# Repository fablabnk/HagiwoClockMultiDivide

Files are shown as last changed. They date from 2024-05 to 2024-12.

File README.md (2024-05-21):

This is an attempt to make a PCB version of [Hagiwo's Clock Multi Divide module](https://note.com/solder_state/n/n8907f2f6e8f5).

# Notes / ToDo

- I'm using the schematic symbol for Arduino Nano v3.x, check that this matches my actual Nano
- Change pin order of Eurocad 2x5 pin power symbol
- Update screw hole positions on panel template - mine fall between two rail screw holes
    - centre is: 3mm down from edge, 5.08mm across from edge, 3.2 in diameter, seems correct

## Diodes and voltage protection

Which diodes protect against which things? Original text says that the circuit:
1. Does not break due to overvoltage
2. Does not break due to negative voltage
3. Does not break due to overcurrent
4. External clock does not enter the internal clock output
5. Internal clock output does not enter the external clock input
But which diodes do which things?

These diodes are there for protecting the arduino if you plug something in that sends voltages it can’t handle.
Everything negative will go to ground thru one set of diodes, everything over 5V will go to the 5V rail thru the other set.
Out has only one diode because there is already one on pin D13.

## Power

- Arduino is given VIN of 12V? Or is it somehow powered from the 5V rail?
- I notice Higawo uses a 16 pin connector
- But Arduino Nano operating range is quoted as 7-12V
- Should we connect capacitors to the +-12V power connector rails?

## Updating the schematic

There were some small issues with the original Hagiwo schematic. I made the following changes in my KiCad schematic:
- in the External Clock In section, there should be a dot connecting two vertical BAT43 diodes
According to the discussion [here](https://lookmumnocomputer.discourse.group/t/arduino-clock-multiple-divider/2612/3), for the Master Clock Out section:
- The initial diode after Arduino pin D13 should be a small signal diode (IN4148 or similiar)
- The SchottKey diode following the 470 Ohm resistor should actually come before the resistor

## PCB Issues

- My SPDT switch is not board mountable and will need to be wired to the board instead. So I used the footprint "TerminalBlock:TerminalBlock_bornier-3_P5.08mm"
- The Arduino nano will be mounted to the front of the PCB using pin headers

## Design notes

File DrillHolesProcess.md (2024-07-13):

# [NEW]

File -> Plot
Choose "Plot Format" SVG
Choose "Drill Marks" -> Actual Size
Tick "Sketch pads on Fabrication Layers"
In "Include Layers" section tick only "F Silkscreen"
In "Plot on All Layers" tick "Edge Cuts"
Set correct output directory at top (relative path)
Click "Plot" button, one file should be generated called "F Silkscreen"
In "Include Layers" section tick only "B Silkscreen"
In "Plot on All Layers" tick nothing
Load both files into Inkscape, tidy, make holes RGB 255 255 255 0 and 0.01mm thick with 75% power and 1 speed. Make silkcreen text RGB 0 0 0 0 and 0.01mm thick with 40% power and 1 speed. The former cuts through, latter cuts surface only
Only the former (front) file has/cuts holes border, the back file should have only silkscreening
Laser cut front file, flip the cut over in place (in the rectangular hole that was created), then laser cut back file

# [OLD] Process for exporting drill holes as SVG format for test laser cutting

In pcb editor choose File -> Plot -> Generate Drill Files: name-NPTH.drl and name-PTH.drl files will be made

double click project_name-NPTH.drl in project file window to open in gerber viewer
File -> Export to PCB Editor
save as NPTH.kicad_pcb
when `Layer Selection` box pops up, click three dots ... and choose Edge.Cuts layer, then click OK
open NPTH.kicad_pcb in project file window, choose File -> Plot, choose Plot Format `SVG`, Include Layers `Edge.Cuts` only and click Plot

repeat above steps for PTH.drl

open each file in SVG

Don't forget to plot also the actual Edge Cuts layer from the original project in the same way as above i.e.
- File -> Plot, choose Plot Format `SVG`, Include Layers `Edge.Cuts` only and click Plot

Now you have three .svg files
project_name-Edge_Cuts.svg
npth-Edge_Cuts.svg
pth-Edge_Cut.svg

Combine in Illustrator and cut all as red thin lines

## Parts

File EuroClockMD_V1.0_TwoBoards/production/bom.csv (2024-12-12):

Designator | Footprint | Quantity | Value | LCSC Part #
A1 | Arduino_Nano | 1 | Arduino_Nano_v3.x
C1, C2 | C_Disc_D3.0mm_W1.6mm_P2.50mm | 2 | 220p
D1, D10, D11, D12, D3, D4, D5, D8 | D_DO-35_SOD27_P7.62mm_Horizontal | 8 | BAT43
D2 | LED_D5.0mm | 1 | GATE OUT 1 LED
D6 | LED_D5.0mm | 1 | GATE OUT 2 LED
D7 | D_DO-35_SOD27_P7.62mm_Horizontal | 1 | IN4148
D9 | LED_D5.0mm | 1 | CLOCK OUT LED
J1 | PJ301M-12_T_S | 1 | GATE OUT 1
J2 | PJ301M-12_T_S | 1 | GATE OUT 2
J3 | PJ301M-12_T_S | 1 | CLOCK OUT
J4 | PJ301M-12_T_S | 1 | EXT CLK IN
J5 | IDC-Header_2x05_P2.54mm_Vertical | 1 | EURO_PWR_2x5
J6 | PinHeader_1x15_P2.54mm_Vertical | 1 | Conn_01x15_Pin_Left
J7 | PinSocket_1x15_P2.54mm_Vertical | 1 | Conn_01x15_Socket_Left
J8 | PinSocket_1x15_P2.54mm_Vertical | 1 | Conn_01x15_Socket_Right
J9 | PinHeader_1x15_P2.54mm_Vertical | 1 | Conn_01x15_Pin_Right
R1, R3, R4, R6, R7, R9 | R_Axial_DIN0207_L6.3mm_D2.5mm_P7.62mm_Horizontal | 6 | 470
R10, R2, R5, R8 | R_Axial_DIN0207_L6.3mm_D2.5mm_P7.62mm_Horizontal | 4 | 22K
RV1 | Alpha9mmPot | 1 | 100K MULTI/DIV
RV2 | Alpha9mmPot | 1 | 100K RATE
SW1 | SW_Slide-03_Wuerth-WS-SLTV_10x2.5x6.4_P2.54mm | 1 | SW_SPDT (Internal Pullup)

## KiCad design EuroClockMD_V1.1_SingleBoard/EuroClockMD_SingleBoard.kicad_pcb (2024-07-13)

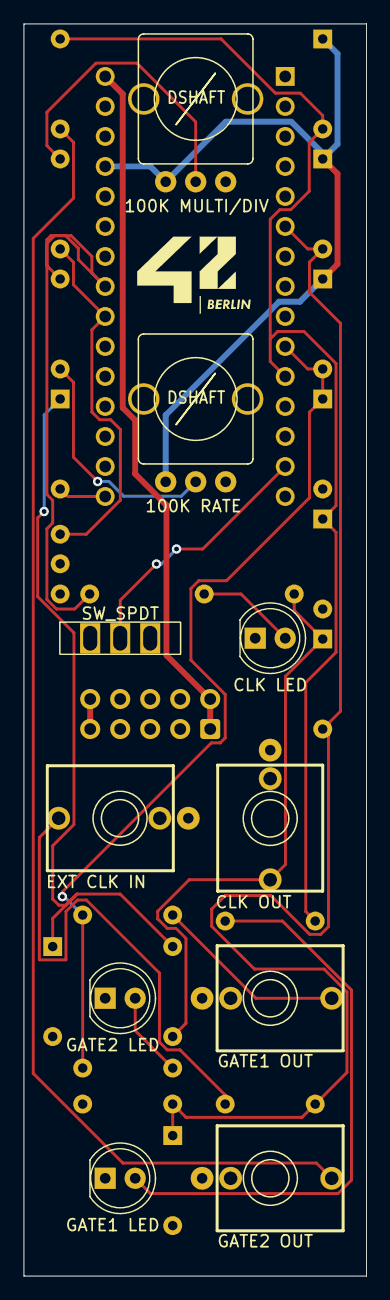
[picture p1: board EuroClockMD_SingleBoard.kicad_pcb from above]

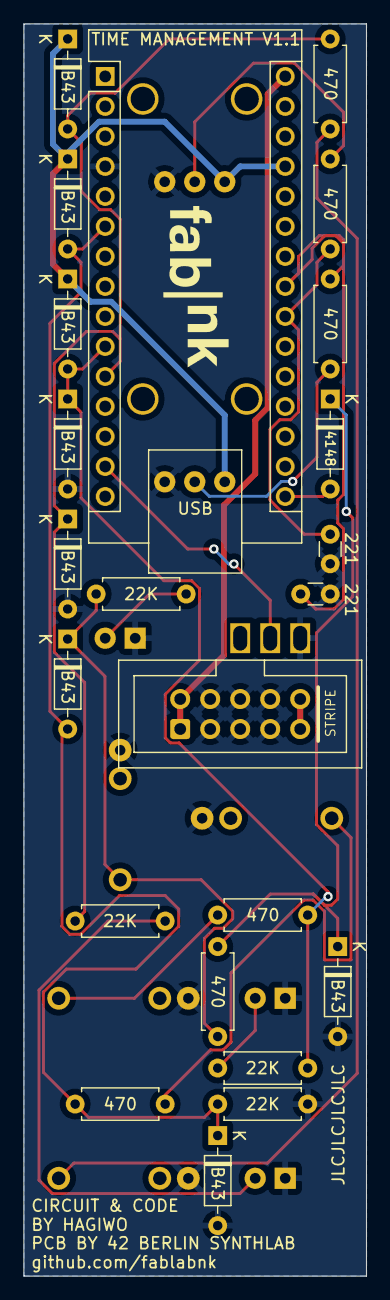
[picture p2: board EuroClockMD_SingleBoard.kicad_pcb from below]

Board: 2 copper layers, 29.0 x 106.0 mm, 33 parts (23 on the bottom side), 20 nets.

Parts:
A1: Arduino_Nano_v3.x; Arduino_Nano
C1, C2: 221; C_Disc_D3.0mm_W1.6mm_P2.50mm
D1, D3, D4, D5, D8, D10, D11, D12: B43; D_DO-35_SOD27_P7.62mm_Horizontal
D2: GATE2 LED; LED_D5.0mm
D6: GATE1 LED; LED_D5.0mm
D7: 4148; D_DO-35_SOD27_P7.62mm_Horizontal
D9: CLK LED; LED_D5.0mm
J1: GATE1 OUT; EighthInch_PJ398SM_T_TN_S
J2: GATE2 OUT; EighthInch_PJ398SM_T_TN_S
J3: CLK OUT; EighthInch_PJ398SM_T_TN_S
J4: EXT CLK IN; EighthInch_PJ398SM_T_TN_S
J5: EURO_PWR_2x5; IDC-Header_2x05_P2.54mm_Vertical_Euro_Power_Striped
R1, R3, R4, R6, R7, R9: 470; R_Axial_DIN0207_L6.3mm_D2.5mm_P7.62mm_Horizontal
R2, R5, R8, R10: 22K; R_Axial_DIN0207_L6.3mm_D2.5mm_P7.62mm_Horizontal
RV1: 100K MULTI/DIV; Pot_9mm_DShaft_RemovedPins4_5
RV2: 100K RATE; Pot_9mm_DShaft_RemovedPins4_5
SW1: SW_SPDT; SW_Slide-03_Wuerth-WS-SLTV_10x2.5x6.4_P2.54mm

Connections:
+5V: A1.27 (+5V), D1.1 (K), D4.1 (K), D10.1 (K), RV1.1, RV2.1
GND: A1.4 (GND), C1.2, C2.2, D2.1 (K), D3.2 (A), D5.2 (A), D6.1 (K), D8.2 (A), D9.1 (K), D11.2 (A), J1.S, J2.S, J3.S, J4.S, J5.3 (GND), J5.4 (GND), J5.5 (GND), J5.6 (GND), J5.7 (GND), J5.8 (GND), R10.2, RV1.3, RV2.3, SW1.2 (B)
unnamed: A1.22 (A3), C1.1, R1.2
unnamed: A1.23 (A4), C2.1, R6.2
unnamed: A1.6 (D3), D10.2 (A), D11.1 (K), D12.2 (A), R9.2, R10.1
unnamed: A1.10 (D7), D3.1 (K), D4.2 (A), R2.2, R3.1
unnamed: A1.11 (D8), D1.2 (A), D5.1 (K), R5.2, R7.1
unnamed: A1.14 (D11), SW1.1 (A)
unnamed: A1.16 (D13), D7.2 (A)
unnamed: A1.30 (VIN), J5.1 (+12V), J5.2 (+12V)
unnamed: D2.2 (A), R2.1
unnamed: D6.2 (A), R5.1
unnamed: D7.1 (K), D8.1 (K), R4.1
unnamed: D9.2 (A), R8.1
unnamed: D12.1 (K), J3.T, R4.2, R8.2
unnamed: J1.T, R3.2
unnamed: J2.T, R7.2
unnamed: J4.T, R9.1
unnamed: R1.1, RV1.2
unnamed: R6.1, RV2.2

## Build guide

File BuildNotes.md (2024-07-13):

- The Arduino should be mounted on pin headers, not soldered directly to the board
- In general, mount and solder the components on the back of the board first
- The one exception is the pin headers, which should be soldered last, as they hinder access to pads for pots
- We also must take care to solder the power connector before soldering the CLK OUT jack
- This is because one pad (S - sleeve) of the CLK OUT cuts into the courtyard of the power connector
- In addition, the CLK OUT S (sleeve) might have to be soldered from front of board (only)

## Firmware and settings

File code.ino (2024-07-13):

//Clock M_D module
#include <MsTimer2.h>

unsigned long ext_count = 400;//タイマーカウント用
unsigned long old_ext_pulse = 0;
unsigned long old_int_pulse = 0;
unsigned long ext_period = 0;//周期
unsigned long ext_count_result = 0;//タイマーのカウント結果
unsigned long old_ext_count_result = 0;//タイマーのカウント結果
byte ext_pulse = 0;//外部クロック　あれば1、なければ0
byte int_pulse = 0;//内部クロック
byte ext_injudge = 1;//外部入力有無判定。あれば1,なければ0。タイマーカウントが規定値超えると判定切り替え
byte old_ext_injudge = 2;

int AD_rate = 512;//rateノブの入力
int rate = 1000;//内部クロック動作時に使用

int AD_MD = 512;//MDノブの入力値
int out_width_ch1 = 10;//アウトプットのパルス幅。
int out_width_ch2 = 10;//アウトプットのパルス幅。
int old_AD_MD = 512;//SW切り替え時のRATE値誤読対策
int MD_ch1 = 5;//マルチプル、ディバイダー判定ch1
int MD_ch2 = 5;//マルチプル、ディバイダー判定ch2
int M_period_ch1 = 0;//マルチプルの時、出力クロックの周期。マルチプルでなければ0とする。
int M_period_ch2 = 0;//マルチプルの時、出力クロックの周期。マルチプルでなければ0とする。
int M_count_ch1 = 1;//マルチプルの時、パルスごとにカウントし、設定値に達すると0に戻る
int M_count_ch2 = 1;//マルチプルの時、パルスごとにカウントし、設定値に達すると0に戻る
int D_count_ch1 = 1;//外部パルスが入るとカウントを位置上げる
int D_count_ch2 = 1;//外部パルスが入るとカウントを位置上げる
int D_full_ch1 = 1;//カウントの上限値
int D_full_ch2 = 1;//カウントの上限値
byte CH1out = 0;//0でLOW出力、1でHIGH出力
byte CH2out = 0;//0でLOW出力、1でHIGH出力
byte M_done_ch1 = 0; //マルチプルの出力確認用。ないと、1クロックで複数パルスでてしまう
byte M_done_ch2 = 0; //マルチプルの出力確認用。ないと、1クロックで複数パルスでてしまう


//---mode切り替え-------------
byte mode_sw = 1;
byte mode = 1;//1=CH1,2=CH2
byte old_mode = 0;//SW切り替え時のRATE値誤読対策
int old_MD_ch1 = 0;//スイッチ切り替え時にディバイダーのクロックが狂うバグ対策
int old_MD_ch2 = 0;//スイッチ切り替え時にディバイダーのクロックが狂うバグ対策

void setup() {
 pinMode(7, OUTPUT); //CH1out
 pinMode(8, OUTPUT); //CH2out
 pinMode(13, OUTPUT); //internal_clock_out
 pinMode(11, INPUT_PULLUP); //SW
 pinMode(3, INPUT); //ext_clock_in
 Serial.begin(9600);

 MsTimer2::set(1, timer_count); // 1ms毎にタイマーカウント
 MsTimer2::start();//外部入力Highになったら、次のHighまでカウント
}

void loop() {
 AD_MD = analogRead(3);
 AD_rate = 1023 - analogRead(4);
 rate = AD_rate * 2 + 100;

 old_ext_pulse = ext_pulse;
 old_int_pulse = int_pulse;
 ext_pulse = digitalRead(3);

 mode_sw = digitalRead(11);
 old_mode = mode;

 old_ext_injudge = ext_injudge;

 //-----------ディバイダー出力のカウントリセット------------
 if (D_count_ch1 >= D_full_ch1) {
   D_count_ch1 = 0;
 }
 if (D_count_ch2 >= D_full_ch2) {
   D_count_ch2 = 0;
 }

 //-----------SWの読み取り---------------

 old_MD_ch1 = MD_ch1;//スイッチ切り替え時にディバイダーのクロックが狂うバグ対策
 old_MD_ch2 = MD_ch2;//スイッチ切り替え時にディバイダーのクロックが狂うバグ対策

 if ( mode_sw == 1  ) {
   mode = 1;
 }
 else if (mode_sw == 0  ) {
   mode = 2;
 }

 if ( old_mode != mode ) {//スイッチ切り替え時にディバイダーのクロックが狂うバグ対策
   old_AD_MD = AD_MD;
 }

 //---------MDノブ判定-----------------------

 if ( mode == 1 && abs(old_AD_MD - AD_MD ) > 30) { //absはスイッチ切り替え時にディバイダーのクロックが狂うバグ対策
   old_AD_MD = 1200;//abs(old_AD_MD - AD_MD ) > 30が絶対に成立するため

   if ( AD_MD >= 0 && AD_MD < 20) {
     MD_ch1 = 9;//*16
   }

   else if ( AD_MD >= 20 && AD_MD < 90) {
     MD_ch1 = 8;//*8
   }

   else if ( AD_MD >= 90 && AD_MD < 240) {
     MD_ch1 = 7;//*4
   }

   else if ( AD_MD >= 240 && AD_MD < 400) {
     MD_ch1 = 6;//*2
   }

   else if ( AD_MD >= 400 && AD_MD < 550) {
     MD_ch1 = 5;//*1
   }

   else if ( AD_MD >= 550 && AD_MD < 700) {
     MD_ch1 = 4;//1/2
   }

   else if ( AD_MD >= 700 && AD_MD < 820) {
     MD_ch1 = 3;//1/3
   }

   else if ( AD_MD >= 820 && AD_MD < 960) {
     MD_ch1 = 2;//1/4
   }

   else if ( AD_MD >= 960 && AD_MD < 1024) {
     MD_ch1 = 1;//1/8
   }
 }

 else if ( mode == 2 && abs(old_AD_MD - AD_MD ) > 30) {  //absはスイッチ切り替え時にディバイダーのクロックが狂うバグ対策
   old_AD_MD = 1200;//abs(old_AD_MD - AD_MD ) > 30が絶対に成立するため

   if ( AD_MD >= 0 && AD_MD < 20) {
     MD_ch2 = 9;//*16
   }

   else if ( AD_MD >= 20 && AD_MD < 90) {
     MD_ch2 = 8;//*8
   }

   else if ( AD_MD >= 90 && AD_MD < 240) {
     MD_ch2 = 7;//*4
   }

   else if ( AD_MD >= 240 && AD_MD < 400) {
     MD_ch2 = 6;//*2
   }

   else if ( AD_MD >= 400 && AD_MD < 550) {
     MD_ch2 = 5;//*1
   }

   else if ( AD_MD >= 550 && AD_MD < 700) {
     MD_ch2 = 4;//1/2
   }

   else if ( AD_MD >= 700 && AD_MD < 820) {
     MD_ch2 = 3;//1/3
   }

   else if ( AD_MD >= 820 && AD_MD < 960) {
     MD_ch2 = 2;//1/4
   }

   else if ( AD_MD >= 960 && AD_MD < 1024) {
     MD_ch2 = 1;//1/8
   }
 }


 switch (MD_ch1) {
   case 1:
     out_width_ch1 = ext_period / 2 / 8;
     M_period_ch1 = ext_period / 8;
     break;

   case 2:
     out_width_ch1 = ext_period / 2 / 4;
     M_period_ch1 = ext_period / 4;
     break;

   case 3:
     out_width_ch1 = ext_period / 2 / 3;
     M_period_ch1 = ext_period / 3;
     break;

   case 4:
     out_width_ch1 = ext_period / 2 / 2;
     M_period_ch1 = ext_period / 2;
     break;

   case 5:
     out_width_ch1 = ext_period / 2 ;
     M_period_ch1 = 0;
     D_full_ch1 = 1;
     break;

   case 6:
     out_width_ch1 = ext_period / 2;
     M_period_ch1 = 0;
     D_full_ch1 = 2;
     break;

   case 7:
     out_width_ch1 = ext_period / 2;
     M_period_ch1 = 0;
     D_full_ch1 = 4;
     break;

   case 8:
     out_width_ch1 = ext_period / 2;
     M_period_ch1 = 0;
     D_full_ch1 = 8;
     break;

   case 9:
     out_width_ch1 = ext_period / 2;
     M_period_ch1 = 0;
     D_full_ch1 = 16;
     break;
 }


 switch (MD_ch2) {
   case 1:
     out_width_ch2 = ext_period / 2 / 8;
     M_period_ch2 = ext_period / 8;
     break;

   case 2:
     out_width_ch2 = ext_period / 2 / 4;
     M_period_ch2 = ext_period / 4;
     break;

   case 3:
     out_width_ch2 = ext_period / 2 / 3;
     M_period_ch2 = ext_period / 3;
     break;

   case 4:
     out_width_ch2 = ext_period / 2 / 2;
     M_period_ch2 = ext_period / 2;
     break;

   case 5:
     out_width_ch2 = ext_period / 2 ;
     M_period_ch2 = 0;
     D_full_ch2 = 1;
     break;

   case 6:
     out_width_ch2 = ext_period / 2 ;
     M_period_ch2 = 0;
     D_full_ch2 = 2;
     break;

   case 7:
     out_width_ch2 = ext_period / 2 ;
     M_period_ch2 = 0;
     D_full_ch2 = 4;
     break;

   case 8:
     out_width_ch2 = ext_period / 2 ;
     M_period_ch2 = 0;
     D_full_ch2 = 8;
     break;

   case 9:
     out_width_ch2 = ext_period / 2 ;
     M_period_ch2 = 0;
     D_full_ch2 = 16;
     break;
 }

 if ( MD_ch1 != old_MD_ch1 || MD_ch2 != old_MD_ch2 ) { //スイッチ切り替え時にディバイダーのクロックが狂うバグ対策
   D_count_ch1 = 0;
   D_count_ch2 = 0;
 }

 //------------外部入力有無判定-------------------------------
 if ( ext_count > 4000 ) { //4s以上カウントが無ければ、外部入力無し判定
   ext_injudge = 0;
 }
 else if ( ext_count < 4000 && ext_pulse == 1 ) {
   ext_injudge = 1;
 }

 if ( old_ext_injudge == 1 && ext_injudge == 0 ) { //外部入力が有→無のとき
   ext_count = 0;
 }


 //---------クロック設定------------------------
 if ( ext_injudge != 0 ) { //外部クロックを使用
   if (ext_pulse == 1 && old_ext_pulse == 0) {
     old_ext_count_result = ext_count_result;//2回の平均取る用
     ext_count_result = ext_count;
     //            ext_count = 0;
     ext_period = (old_ext_count_result + ext_count_result) / 2;//外部入力周期。ばらつき低減のため2回の平均値
     //      MsTimer2::start();//外部入力Highになったら、次のHighまでカウント
   }
 }
 else if ( ext_injudge == 0) { //内部クロックを使用
   ext_period = rate;
   if ( ext_count < 5 || ext_count >= ext_period) {
     int_pulse = 1;
   }
   else if (ext_count >= 5 ) {
     int_pulse = 0;
   }

 }
 //--------------INTERNAL CLOCK出力（外部入力無い場合のみ）-----------

 if ( int_pulse == 1 ) {
   digitalWrite(13, HIGH);
 }
 else if ( ext_count >= ext_period / 2  ) {
   digitalWrite(13, LOW);
 }

 //-----------------OUT1出力------------------
 if (ext_pulse == 1 && old_ext_pulse == 0) {//外部クロック用
   D_count_ch1 ++;
   ext_count = 0;
   M_count_ch1 = 0;
   M_done_ch1 = 0;
   if ( MD_ch1 <= 4 ) {
     digitalWrite(7, HIGH);
     CH1out = 1;
   }
 }

 if (int_pulse == 1 && old_int_pulse == 0) {//内部クロック用
   D_count_ch1 ++;
   ext_count = 0;
   M_count_ch1 = 0;
   M_done_ch1 = 0;
   if ( MD_ch1 <= 4 ) {
     digitalWrite(7, HIGH);
     CH1out = 1;
   }
 }

 if ( MD_ch1 < 5 ) {
   if ( ext_count  >= M_period_ch1  * M_count_ch1  && CH1out == 0) {
     CH1out = 1;
     digitalWrite(7, HIGH);
   }
   if ( ext_count >= M_period_ch1  * M_count_ch1 + out_width_ch1  && CH1out == 1 ) {
     digitalWrite(7, LOW);
     M_count_ch1 ++;
     CH1out = 0;
   }
 }

 else if ( MD_ch1 == 5 ) {
   if (D_count_ch1 == 1 && M_done_ch1 == 0) {
     CH1out = 1;
     M_done_ch1 = 1;
     digitalWrite(7, HIGH);
   }
   if ( ext_count >=  out_width_ch1   ) {
     digitalWrite(7, LOW);
     CH1out = 0;
   }
 }

 else if ( MD_ch1 > 5 ) {
   if (D_count_ch1 == 1 && M_done_ch1 == 0) {
     CH1out = 1;
     digitalWrite(7, HIGH);
     M_done_ch1 = 1;
   }
   if ( ext_count >=  out_width_ch1   ) {
     digitalWrite(7, LOW);
     CH1out = 0;
   }
 }


 //-----------------OUT2出力------------------
 if (ext_pulse == 1 && old_ext_pulse == 0) {
   D_count_ch2 ++;
   M_count_ch2 = 0;
   M_done_ch2 = 0;
   if ( MD_ch2 <= 4 ) {
     digitalWrite(8, HIGH);
     CH2out = 1;
   }
 }

 if (int_pulse == 1 && old_int_pulse == 0) {//内部クロック用
   D_count_ch2 ++;
   M_count_ch2 = 0;
   M_done_ch2 = 0;
   if ( MD_ch2 <= 4 ) {
     digitalWrite(8, HIGH);
     CH2out = 1;
   }
 }

 if ( MD_ch2 < 5 ) {
   if ( ext_count  >= M_period_ch2  * M_count_ch2  && CH2out == 0) {
     CH2out = 1;
     digitalWrite(8, HIGH);
   }
   if ( ext_count >= M_period_ch2  * M_count_ch2 + out_width_ch2  && CH2out == 1 ) {
     digitalWrite(8, LOW);
     M_count_ch2 ++;
     CH2out = 0;
   }
 }

 else if ( MD_ch2 == 5 ) {
   if (D_count_ch2 == 1 && M_done_ch2 == 0) {
     CH2out = 1;
     M_done_ch2 = 1;
     digitalWrite(8, HIGH);
   }
   if ( ext_count >=  out_width_ch2   ) {
     digitalWrite(8, LOW);
     CH2out = 0;
   }
 }

 else if ( MD_ch2 > 5 ) {
   if (D_count_ch2 == 1 && M_done_ch2 == 0) {
     CH2out = 1;
     M_done_ch2 = 1;
     digitalWrite(8, HIGH);
   }
   if ( ext_count >=  out_width_ch2   ) {
     digitalWrite(8, LOW);
     CH2out = 0;
   }
 }


 //開発用

 Serial.print(ext_count);
 Serial.print(",");
 Serial.print(CH1out * 500);
 Serial.print(",");
 Serial.print(D_count_ch1 * 80);
 Serial.println("");

}

//タイマーカウント。1ms毎にカウントを増やす
void timer_count() {
 ext_count ++;
}

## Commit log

2024-04-03 First sketch of schematic completed with footprints
    [EuroClockMD.kicad_pcb, EuroClockMD.kicad_sch]
2024-06-01 pushing latest updates
    [EuroClockMD-BOM.csv]
2024-07-13 Completed v1.1 - single board version with correct power header orientation, ground plane and corrected panel holes sizes (LEDs)
    [BOM.csv, EuroClockMD-BOM.csv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]
2024-08-13 latest updates
    [EuroClockMD_TwoBoards_Panel.kicad_pcb]
2024-12-12 updating after a while dormant
    [bom.csv, designators.csv, positions.csv]
